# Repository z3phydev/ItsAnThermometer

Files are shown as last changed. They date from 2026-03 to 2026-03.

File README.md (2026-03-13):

# ItsAnThermometer
Its a simple Thermometer... what did you expect. It has 3 leds for tempature (under 20 for blue, 20-24 for green and over 24 for red. But can be changed) powered but a XIAO RP2040
## How to use
1. Build it
2. Flash circutpython to the XIAO
3. Upload main.py to it
4. Plug in or add 4x AA batteries
6. Observe

You can use the toggle switch to change the power source

## Why did I make it
I was sick so I was off school and had 2 days to make something and I needed one. Also it is to show my little brother eletronics.

## Schematic



## PCB



## 3D Model

ThermometerPLAN
ThermometerISO
ThermometerWDISO

## BOM

|Reference(s)|Qty|Value/Description |MFR |MFR No. |Mouser No. |Unit Price GBP |Total Price GBP|Link |FIELD10 |FIELD11 |FIELD12 |
|---|---|---|---|---|---|---|---|---|---|---|---|
|~ |5  |PCB and Partial assebly |JLCPCB |~ |~ |~ |2.46 |https://jlcpcb.com/ | | | |
|U2 |1  |Seeed XIAO RP2040 with Headers|Raspberry Pi |102010630 |713-102010630 |3.9 |3.9 |https://www.mouser.co.uk/ProductDetail/Seeed-Studio/102010630?qs=sqEgtWRSLJ0HHL%252BkmwiGyA%3D%3D | | | |
|U1 |1  |LM35 Temp sensor |Texas Instruments |LM35DZ/LFT1 |926-LM35DZ/LFT1 |1.26 |1.26 |https://www.mouser.co.uk/ProductDetail/Texas-Instruments/LM35DZ-LFT1?qs=QbsRYf82W3H30AtKgrS0IA%3D%3D | | | |
|BT1 |1  |4x AA Battey Holder |Keystone Electronics |2477 |534-2477 |1.6 |1.6 |https://www.mouser.co.uk/ProductDetail/Keystone-Electronics/2477?qs=Q3RoVmURDolEbXnNenQutg%3D%3D | | | |
|R2, R3 |2  |10ohm resistor |YAGEO |MF0207FTE52-75R|603-MF0207FTE52-75R|0.08 |0.16 |https://www.mouser.co.uk/ProductDetail/YAGEO/MF0207FTE52-10R?qs=Is6ZsIPfHkZVWUebLBVbaw%3D%3D | | | |
|R1 |1  |75ohm resistor |YAGEO |MF0207FTE52-75R|603-MF0207FTE52-75R|0.08 |0.08 |https://www.mouser.co.uk/ProductDetail/YAGEO/MF0207FTE52-75R?qs=KUIzHt%2Fe91nXiKietXMfvA%3D%3D | | | |
|SW1 |1  |SPDT Switch |E-Switch |100SP1T1B4M2QE |612-100-A1421 |1.97 |1.97 |https://www.mouser.co.uk/ProductDetail/E-Switch/100SP1T1B4M2QE?qs=YXf4ACKMM4xJ0mJK%2FyIa1g%3D%3D | | | |
|J1 |1  |USB A Port |Molex |67643-0910 |538-67643-0910 |1.12 |1.12 |https://www.mouser.co.uk/ProductDetail/Molex/67643-0910?qs=EuyFtE1skifNhj6pwWTsXw%3D%3D | | | |
|C1 |1  |100nF Capacitor |Vishay / BC Components |K104K15X7RF5WH5|594-K104K15X7RF5WH5|0.17 |0.17 |https://www.mouser.co.uk/ProductDetail/Vishay-BC-Components/K104K15X7RF5WH5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| | | |
|D4, D5 |2  |Schottky Diode |Vishay General Semiconductor|SB140-E3/73 |625-SB140-E3/73 |0.14 |0.28 |https://www.mouser.co.uk/ProductDetail/Vishay-General-Semiconductor/SB140-E3-73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| | | |
|U3 |1  |AMS1117-3.3 Breakout Board |Texas Instruments |~ |~ |1.26 |1.26 |https://www.aliexpress.com/item/1005007091283048.html | | | |
|D1, D2, D3  |3  |Coloured LEDs |~ |~ |~ |(In a 450pcs pack)|0.76 |https://www.aliexpress.com/item/1005008664239729.html | | | |
|~ |2  |Screw 6 mm M3 |RND |610-00421 |~ |(In 200pcs pack)  |0.74 |https://uk.rs-online.com/web/p/machine-screws/0492499 | | | |
|~ |1  |10cm x 10cm MDF 12mm Thick |MEDITE |~ |~ |2 |2 |https://www.cutmy.co.uk/wood/mdf-board/standard/12mm/L100-W100/ | | | |
| | | | | | | | | | | | |
| | | | | | | | | | |Total Price USD approx|Total Price GBP|
| | | | | | | | | |Items |23.7 |17.76 |
| | | | | | | | | |Shipping (and fees)|24.72 |18.52 |
| | | | | | | | | |Final |48.42 |36.28 |

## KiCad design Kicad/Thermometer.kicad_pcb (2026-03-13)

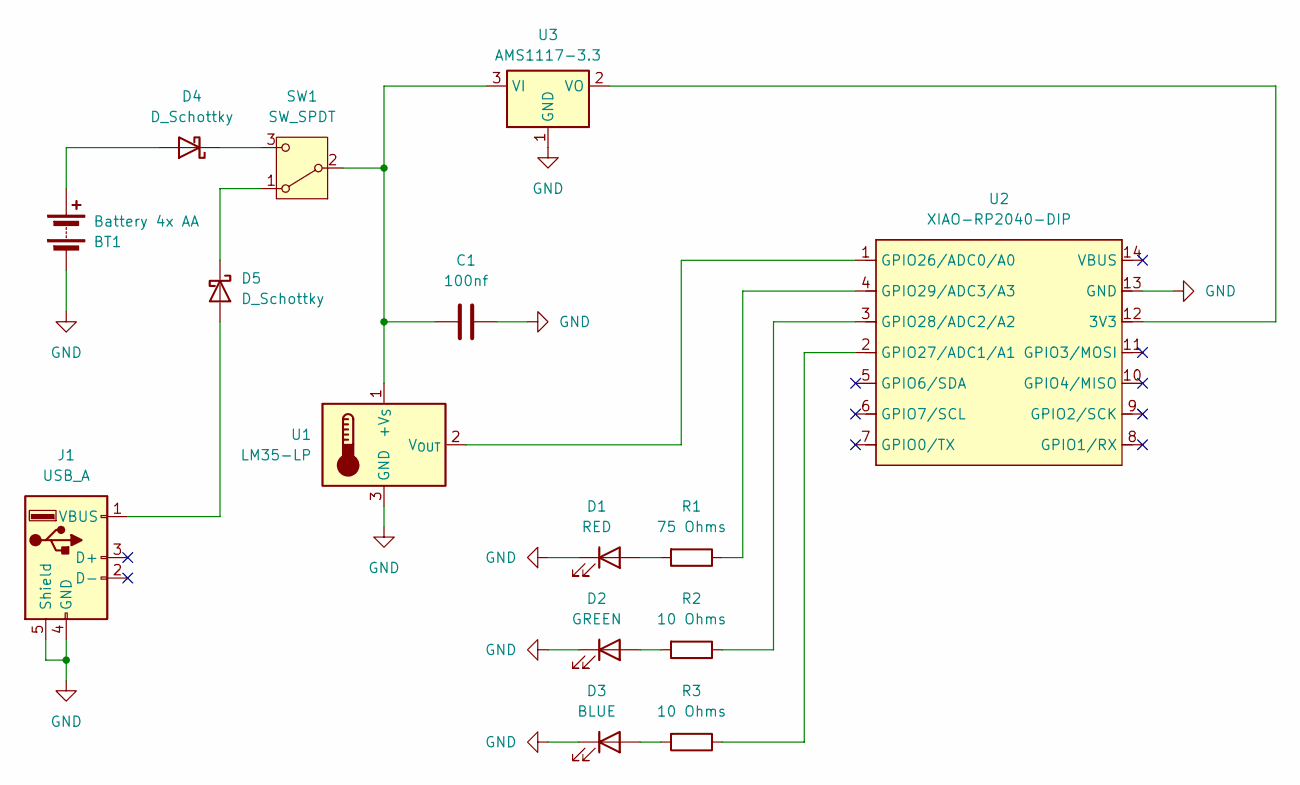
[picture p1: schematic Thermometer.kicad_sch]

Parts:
BT1: Battery 4x AA; BAT_2477
C1: 100nf; C_Disc_D4.3mm_W1.9mm_P5.00mm
D1: RED; LED_D5.0mm
D2: GREEN; LED_D5.0mm
D3: BLUE; LED_D5.0mm
D4, D5: D_Schottky; D_DO-41_SOD81_P10.16mm_Horizontal
J1: USB_A; USB_A_Molex_67643_Horizontal
R1: 75 Ohms; R_Axial_DIN0207_L6.3mm_D2.5mm_P10.16mm_Horizontal
R2, R3: 10 Ohms; R_Axial_DIN0207_L6.3mm_D2.5mm_P10.16mm_Horizontal
SW1: SW_SPDT; SW_100SP1T1B4M2QE
U1: LM35-LP; TO-92_Wide
U2: XIAO-RP2040-DIP
U3: AMS1117-3.3; AMS1117Breakout

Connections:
GND: BT1.N (-), C1.2, D1.1 (K), D2.1 (K), D3.1 (K), J1.4 (GND), J1.5 (Shield), U1.3 (GND), U2.13 (GND), U3.1 (GND)
unnamed: BT1.P (+), D4.2 (A)
unnamed: D1.2 (A), R1.2
unnamed: D2.2 (A), R2.2
unnamed: D3.2 (A), R3.2
unnamed: D4.1 (K), SW1.3 (C)
unnamed: D5.2 (A), J1.1 (VBUS)
unnamed: D5.1 (K), SW1.1 (A)
unnamed: C1.1, SW1.2 (B), U1.1 (+V_{S}), U3.3 (VI)
unnamed: U1.2 (V_{OUT}), U2.1 (GPIO26/ADC0/A0)
unnamed: U2.12 (3V3), U3.2 (VO)
unnamed: R3.1, U2.2 (GPIO27/ADC1/A1)
unnamed: R2.1, U2.3 (GPIO28/ADC2/A2)
unnamed: R1.1, U2.4 (GPIO29/ADC3/A3)

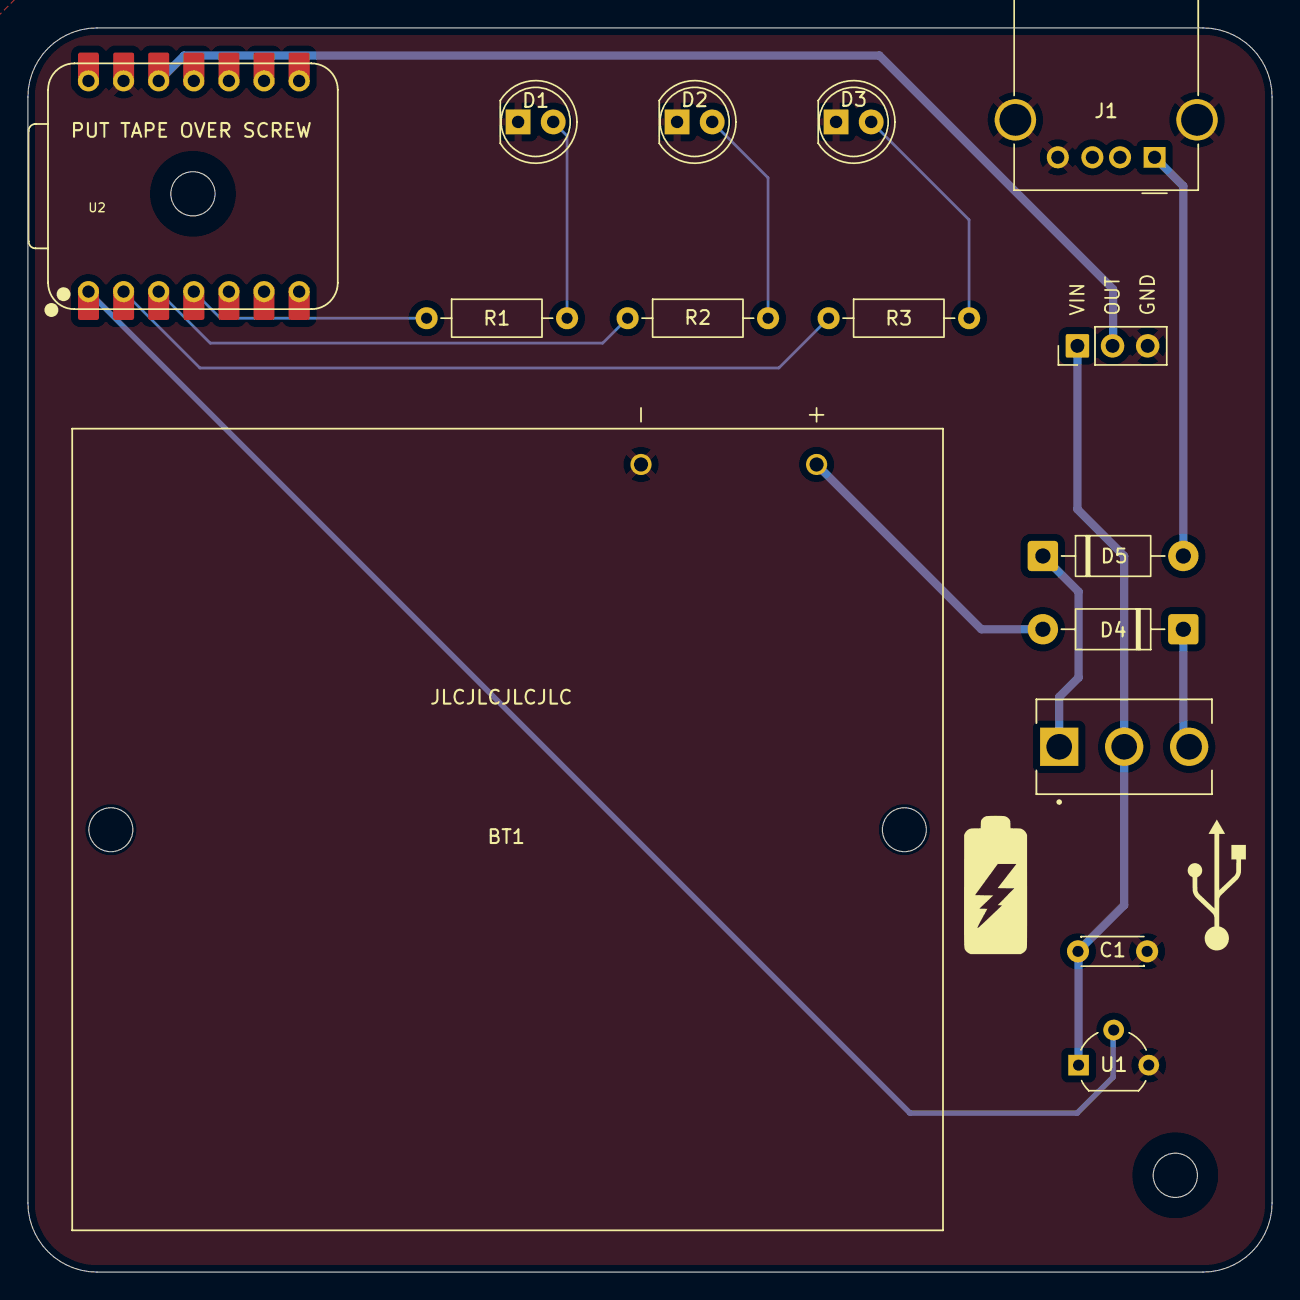
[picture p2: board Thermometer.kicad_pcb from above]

Board: 2 copper layers, 90.0 x 90.0 mm, 15 parts (0 on the bottom side), 14 nets.

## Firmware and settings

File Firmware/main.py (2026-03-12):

import time
import board
import analogio
import digitalio

sensor = analogio.AnalogIn(board.A0)

red = digitalio.DigitalInOut(board.D29)
red.direction = digitalio.Direction.OUTPUT

green = digitalio.DigitalInOut(board.D28)
green.direction = digitalio.Direction.OUTPUT

blue = digitalio.DigitalInOut(board.D27)
blue.direction = digitalio.Direction.OUTPUT

def get_voltage(pin):
    return (pin.value * 3.3) / 65535

while True:
    voltage = get_voltage(sensor)

    temp_c = voltage / 0.01

    if temp_c > 24:
        red.value = True
        green.value = False
        blue.value = False

    elif 21 <= temp_c <= 24:
        red.value = False
        green.value = True
        blue.value = False

    else:
        red.value = False
        green.value = False
        blue.value = True

    time.sleep(0.5)

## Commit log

2026-03-12 Revise README with project details and instructions
    Updated project name and added usage instructions, schematic, PCB, 3D model images, and BOM section.
2026-03-12 Update schematic image in README.md
2026-03-12 Implement temperature-based LED control in main.py
